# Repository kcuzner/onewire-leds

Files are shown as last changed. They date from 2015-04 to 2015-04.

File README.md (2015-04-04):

# One-wire LED

## Purpose

This project is part of a larger team design project. This particular portion
is an RGB LED controlled by its own power wire using a variant of the 1-wire
protocol.

## Protocol

The standard 1-wire protocol uses only two lines: power and ground. Data is
transmitted to and from slave devices by a master device by toggling the power
line low for short periods of time. The slave devices maintain their power
during these short losses using a diode-capacitor rectifier circuit. However,
this protocol is not suitable for devices requiring more than a few hundred
microamps due to the fact that a large pullup resistor is used on the power
line and drawing too much current causes an unacceptable voltage drop.

This device uses a modified version of the protocol that sacrifices the
bi-directionality of the protocol for the ability to supply comparatively large
amounts of current to attached devices. This is accomplished by using a
P-channel MOSFET to switch the power off on the master side in short intervals.
No pull-up resistor is used and there is no corresponding open collector
transistor on the slave devices (thus removing the bi-directional capability).
So long as the capacitor on the slave side of the bus is large enough to
sustain their individual current draw, the bus can provide both data and power
to devices requiring several several 10s of milliamps of current to operate
property (such as an RGB led controller).

This protcol has been modified from the actual 1-wire specification to be
simpler to use with a 100KHz tick rate on the master in addition to necessary
modifications due to the loss of bidirectionality.

The protocol is as follows:
 * A reset is performed by holding the line low for 480uS. This device will
   listen for a continuously low input for the full 480uS without any additional
   edges. The master should allow the line to float for another 480uS. Normally,
   the presence pulse would be read during this time. However, there is no
   presence pulse in this system.
 * Following a reset, A falling edge must occur within 70uS. This marks the
   start of the LSB of the transmitted byte.
 * To write a 0, the master brings the line low for 60uS. The slave will sample
   between 20-30uS following the falling edge. Following this, the master will
   allow the line to float for 10uS before beginning the next bit.
 * To write a 1, the master brings the line low for 10uS and releases it. The
   slave will sample between 20-30uS following the falling edge. The master will
   allow the line to float for 60uS after the initial low pulse.
 * A transaction consists of the reset pulse following by 8 write pulses.

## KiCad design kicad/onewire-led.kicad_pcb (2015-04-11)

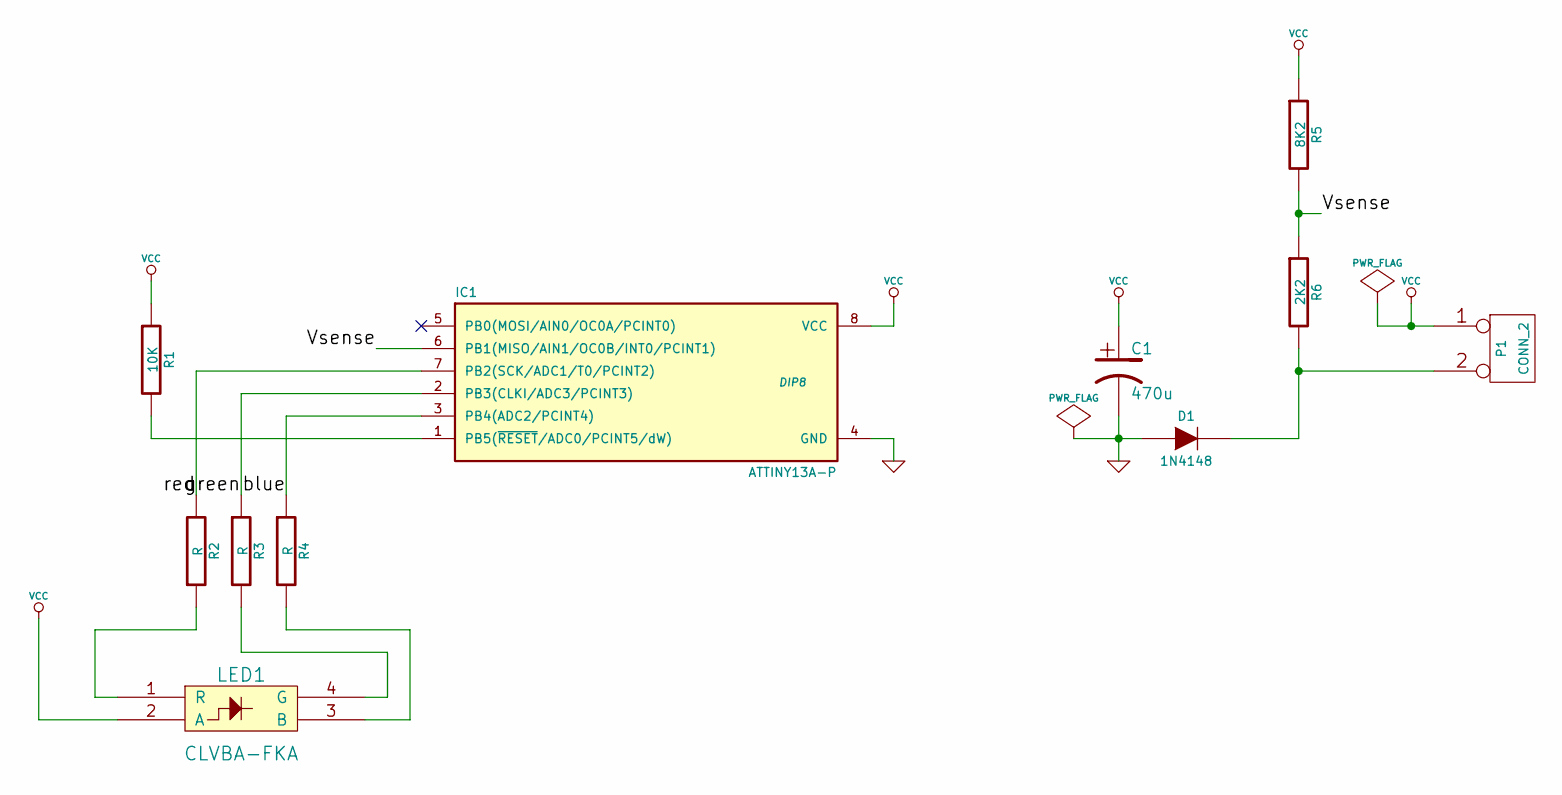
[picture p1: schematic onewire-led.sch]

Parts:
C1: 470u
D1: 1N4148
IC1: ATTINY13A-P; DIP8
LED1: CLVBA-FKA
P1: CONN_2
R1: 10K
R2, R3, R4: R
R5: 8K2
R6: 2K2

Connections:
/Vsense: IC1.6 (PB1(MISO/AIN1/OC0B/INT0/PCINT1)), R5.2, R6.1
/blue: IC1.3 (PB4(ADC2/PCINT4)), R4.1
/green: IC1.2 (PB3(CLKI/ADC3/PCINT3)), R3.1
/red: IC1.7 (PB2(SCK/ADC1/T0/PCINT2)), R2.2
GND: C1.2, D1.1 (A), IC1.4 (GND)
unnamed: LED1.3 (B), R4.2
unnamed: IC1.1 (PB5(~RESET~/ADC0/PCINT5/dW)), R1.2
unnamed: LED1.1 (R), R2.1
unnamed: LED1.4 (G), R3.2
unnamed: D1.2 (K), P1.2 (PM), R6.2
VCC: C1.1, IC1.8 (VCC), LED1.2 (A), P1.1, R1.1, R5.1

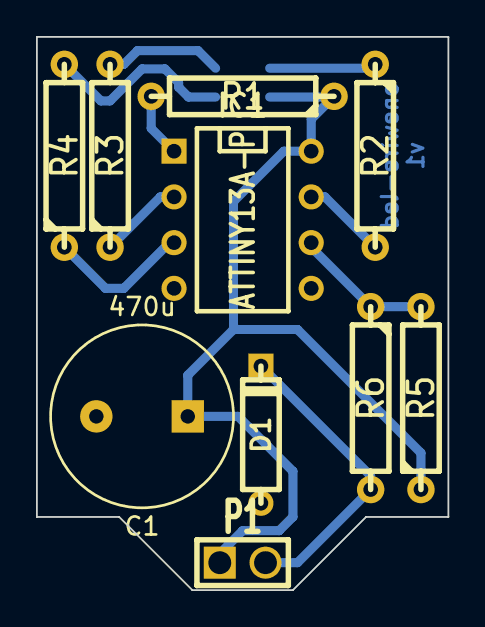
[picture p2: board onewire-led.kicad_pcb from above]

Board: 2 copper layers, 22.9 x 30.7 mm, 11 parts (1 on the bottom side), 11 nets.

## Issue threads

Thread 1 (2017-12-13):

ATTiny10

MaurinElectroTextile, 2017-12-13:
Do you think that your code can fit in the ATTiny10?
http://www.atmel.com/images/atmel-8127-avr-8-bit-microcontroller-attiny4-attiny5-attiny9-attiny10_datasheet.pdf
I'm interested to use it to drive 60 mA LED.

kcuzner, 2017-12-15:
## Firmware Perspective

At first glance, I see no reason this couldn't be used on an ATTiny10 since it has the required peripherals and space:

- 1024 bytes flash
- Pin rising edge interrupt
- A timer

However, it should be noted that the ATTiny10 has a 16-bit counter, while the ATTiny13A only had 8 bits. You will need to recompute the constants `ONEWIRE_RESET_TICKS` and `ONEWIRE_READ_TICKS`. You may also end up having to either adjust the prescaler or use a initial value in the timer to prevent overflow from taking too long.

## Hardware perspective

Let's look at the schematic. I'm going to assume you've read up on the 1-wire protocol and how it is usually driven. The 1-wire signal will be applied to P1 (ground to pin 2, signal to pin 1).

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

The input connector P1 has its pins in one of two states:

- The voltage on pin 1 is greater than pin 2. In this state, the diode is forward biased (note that GND is 0.7V relative to pin 2. The capacitor now charges. The main issue here will be with your driver. Generally 1-wire uses a pullup of somewhere beween 5K and 1K. At its worst case, your LED will try to draw 60mA from that 1K pullup, which will basically drive the voltage across P1 to zero. **You will need to use a fairly strong, push-pull driver for your 1-wire circuit**. I think something like a standard gate driver used as a buffer could fit your needs (look at the MCP1402 for an example). **Important note:** This only works because the microcontroller never responds back to whatever is driving P1. You can't have the microcontroller respond and have this super-strong driver. Because of the resistor divider R5/R6 you won't blow anything up, but the driving source is so strong you can never hope to pull it down to send a message back to the master. You'll have to get a bit more creative if you need bi-directional communication (maybe only using the driver during idle times and using a pull-up+open-drain setup for the rest of the times, etc).
- The voltage on pin 1 is equal to pin 2. This is the zero state, no charging is occurring. The issue here will be with the size of the capacitor. You will need to make sure it is big enough to sustain the 60mA drive current long enough so that the microcontroller doesn't shut off. I *think* 470uF is more than big enough for the 500uS that it takes for the one-wire bus to reset, assuming you charge the capacitor very quickly afterwards with your driver.

**Now, there is one other issue: Brown-out.** This device is *designed* to brown-out since it runs off a capacitor that is slowly discharging. I could not find any mention of a brown-out detect circuit on the ATTiny10, so you may need to provide your own (please read [this application note](http://www.atmel.com/Images/doc1051.pdf) by Atmel about building an external brownout detection circuit). If you do not provide some way to reset the device when the power dips too low, you will get undefined behavior and the microcontroller will misbehave. The device may not respond to onewire commands or may do something really strange.

MaurinElectroTextile, 2018-02-26:
Following your advices you will find the code for ATTiny10 on this repository https://github.com/eTextile/Lulu/tree/master/Software I decide to focus on safe solution with three wires. It is still work in progress but any advices are welcome.

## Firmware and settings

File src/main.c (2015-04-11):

/**
 * 1-Wire LED
 */
#include "leds.h"
#include "onewire.h"

#include <avr/pgmspace.h>
#include <avr/io.h>
#include <avr/interrupt.h>
#include <avr/wdt.h>

#define N_CHANNELS 16
#define OFF_TIME   0xFFFF

#define GET_CHAN(V)  (V & 0x0F)
#define GET_BLINK(V) (V & 0x10)

#define GET_RED(V)   ((V & 0xFF0000) >> 16)
#define GET_GREEN(V) ((V & 0x00FF00) >> 8)
#define GET_BLUE(V)  (V & 0x0000FF)

/**
 * Fuse data for this program to work properly on the ATTiny13A
 */
#ifdef __AVR_ATtiny13A__
FUSES = {
    .low = (FUSE_SPIEN & FUSE_SUT0 & FUSE_CKSEL0), //9.6MHz, no ckdiv8
    .high = (FUSE_BODLEVEL1) //brown out at 2.7V
};
#else
#error "No fuses defined for selected processor"
#endif

/**
 * Channel color values in 24-bit format
 */
static const uint32_t PROGMEM channel_colors[N_CHANNELS] = {
    0xff0000, //channel 1
    0xff9900,
    0xccff00,
    0x33ff00,
    0x00ff66,
    0x00ffff,
    0x0066ff,
    0x3300ff,
    0xcc00ff,
    0xff0099, //channel 10
    0xff0099, //overflow
    0xff0099, //overflow
    0xff0099, //overflow
    0xff0099, //overflow
    0xff0099, //overflow
    0xff0099 //overflow
};

int main(void)
{
    uint8_t val, chan;
    uint32_t color;
    uint16_t i;

    wdt_enable(WDTO_15MS);

    leds_init();
    onewire_init();

    //delay at the beginning to ensure we have a steady supply before turning on the LEDs
    for (i = 0; i < OFF_TIME; i++)
    {
        wdt_reset();
    }

    DDRB |= (1<<0);

    sei();

    while(1)
    {
        wdt_reset();
        leds_tick();

        if (onewire_has_new_byte())
        {
            val = onewire_read_byte();
            chan = GET_CHAN(val);
            color = pgm_read_dword(&channel_colors[chan]);
            leds_set_color(GET_RED(color), GET_GREEN(color), GET_BLUE(color));
            if (GET_BLINK(val))
            {
                leds_begin_off(OFF_TIME);
            }
        }
    }

    return 0;
}

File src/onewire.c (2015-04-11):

/**
 * Modified 1-Wire Protocol
 */
#include "onewire.h"

#include <avr/interrupt.h>

#define ONEWIRE_PIN_MASK (1<<ONEWIRE_PIN)
#define ONEWIRE_PIN_VALUE (ONEWIRE_INPUT & ONEWIRE_PIN_MASK)

//timer 0 is used for our timing. The presecaler is set at CLK/64 so that
//we get a period of 6 2/3uS per tick given a 9.6MHz clock.
//480uS: 72 ticks
//70uS: 11 ticks
//4 ticks is our sample time after a falling edge, landing at about 26uS
// - NOTE: This is equivalent to 256 clock cycles, giving us ample
//   computation time
#define ONEWIRE_RESET_TICKS 68
#define ONEWIRE_READ_TICKS  4

// state machine states
// TODO: Make sure that a reset during a read or immediately following another reset is registered as a reset
typedef enum { ST_IDLE, ST_BEGIN_RESET, ST_RESET, ST_READ, ST_DONE } state_t;

static volatile uint8_t byte_flag = 0;
static volatile uint8_t finished_byte = 0;
static volatile uint8_t current_byte = 0;
static volatile uint8_t next_bit = 0;

static volatile state_t state = ST_IDLE;


void onewire_init(void)
{
    //we want an input on our pin
    ONEWIRE_DDR &= ~ONEWIRE_PIN_MASK;

    //interrupt on rising edges of INT0
    MCUCR &= 0xFC; //clear bottom two bits
    MCUCR |= (1<<ISC01) | (1<<ISC00); //ISC01 = 1, ISC00 = 1 => interrupt on rising edge
    GIMSK |= (1<<INT0);

    TCCR0A = 0; //normal operation
    TCCR0B = (1<<CS01) | (1<<CS00); //clock source is clk/64
    TIMSK0 = (1<<OCIE0B) | (1<<OCIE0A) | (1<<TOIE0); //enable all interrupts for the timer

    //since the timer is reset to 0 on a falling edge, we can use the following:
    //interrupt A: Time to sample!
    //interrupt B: A reset has just occurred if the line is still low, otherwise its been too long since the last falling edge
    //overflow: It's been too long since the last falling edge
    OCR0A = ONEWIRE_READ_TICKS;
    OCR0B = ONEWIRE_RESET_TICKS;
}

uint8_t onewire_has_new_byte(void)
{
    return byte_flag;
}

uint8_t onewire_read_byte(void)
{
    byte_flag = 0;
    return finished_byte;
}

//falling edge
ISR(INT0_vect)
{
    if (ONEWIRE_PIN_VALUE)
    {
        //every falling edge resets the timer
        TCNT0 = 0;

        PORTB |= (1<<0);

        switch(state)
        {
        case ST_IDLE:
            state = ST_BEGIN_RESET;
            break;
        case ST_RESET:
            //we are now reading a byte
            state = ST_READ;
            break;
        case ST_DONE:
            //we are now idle
            state = ST_IDLE;
            break;
        default:
            break;
        }
    }
}

//compare A: 26uS since last falling edge
ISR(TIM0_COMPA_vect)
{
    switch(state)
    {
    case ST_READ:
        //it is time to sample
        current_byte >>= 1;
        if (!ONEWIRE_PIN_VALUE) //inverted values for our ground-based bus (0 = 1)
            current_byte |= 0x80; //LSB first
        next_bit++;
        if (next_bit > 7)
        {
            //we are done reading. We wait for the next reset
            state = ST_DONE;
            //we have a byte!
            finished_byte = current_byte;
            byte_flag = 1;
        }
        break;
    default:
        break;
    }
}

//compare B: 480uS since last falling edge or since last timer overflow
ISR(TIM0_COMPB_vect)
{
    switch(state)
    {
    case ST_BEGIN_RESET:
        if (ONEWIRE_PIN_VALUE)
        {
            PORTB &= ~(1<<0);
            //still high? we have a reset
            state = ST_RESET;
            current_byte = 0;
            next_bit = 0;
        }
        else
        {
            state = ST_IDLE;
        }
        break;
    default:
        //it's been too long since the last falling edge
        state = ST_IDLE;
        break;
    }
}

ISR(TIM0_OVF_vect)
{
    switch(state)
    {
    case ST_RESET:
        //we don't mind overflowing the timer here
        break;
    default:
        //It's been too long since the last falling edge
        state = ST_IDLE;
        break;
    }
}

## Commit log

2015-04-04 Added LED PWM state machine and size output to Makefile
2015-04-04 Added one-wire scaffold and color selection code
2015-04-04 Added fuse programming via avr/fuses.h to Makefile
2015-04-05 Added initial methods for turning off the LEDs for a time
2015-04-05 Added interrupt enable instruction
2015-04-05 Fixed a missing break statement
    [onewire.c]
2015-04-07 Fixed watchdog timer problems and some LED logic issues
    We are going to use the WDT, but because it's easier to work with it
    than try to work against it.
    [main.c]
2015-04-07 Moved pins around to avoid damaging the test board
    [leds.h]
2015-04-07 Fixed one-wire configuration for a working system
    It's working...it's working!!!
    [leds.h, main.c, onewire.c]
2015-04-07 Fixed LED state machine for inverted values
2015-04-10 Added initial schematic without ground fills
    [onewire-led.kicad_pcb, onewire-led.sch]
2015-04-10 Added ground fill to bottom copper
    [onewire-led.kicad_pcb]
2015-04-11 Fixed layout for package sizes and incorrect PLCC layout
    [onewire-led.kicad_pcb, onewire-led.sch]
2015-04-11 Reversed polarity of the onewire bus for our application
    [onewire.c]
2015-04-11 Added reset toggle for debug and enabled BOD
    Turns out, BOD is important with an unreliable power supply, such as
    seen hen doing a drop-in LED replacement like this board
    [main.c, onewire.c]
